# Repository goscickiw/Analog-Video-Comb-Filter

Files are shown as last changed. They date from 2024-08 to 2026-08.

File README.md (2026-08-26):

# Analog-Video-Comb-Filter
Analog Composite Video to S-Video comb filter board using SAA4960, SAA4961 or SAA4963 integrated circuit.

## **WARNING**
**This project uses end-of-life components that are no longer manufactured. If you want to build this, make sure that you can obtain all components before starting. Used or new-old-stock parts can sometimes be found online.**

## Description

This is a fully analog alternative to digital comb filters such as Extron YCS Transcoder or YCS 100. [That doesn't mean it will give better results though](#image-comparison---no-filter-lc-filter-and-comb-filters). I just made it because I didn't find any fully analog device like that on the market and I wanted one.

The comb filter is used to convert a composite video signal into an S-Video (Y/C) signal. Comb filters are much better than passive LC filters usually built into composite video displays, as they can preserve the frequencies of luminance that overlap with chrominance, providing higher image detail while removing dot crawl, and remove those overlapping luminance frequencies from the chrominance signal which reduces color artifacts.

When using the SAA4960 integrated circuit, PAL B, D, G, H and I systems are supported.

SAA4961 provides aditional support for PAL M, N and NTSC M systems.

When using the SAA4963 integrated circuit, only the NTSC M system is supported.

The board is designed to fit inside a KRADEX Z-76 enclosure.

### Circuit description

Circuit diagram

A composite video signal is fed in through an RCA connector (J4). The signal is terminated with a 75 ohm resistor and fed to U3 (or U7), U4 and U6 through 100 nF capacitors.

The LM1881 sync separator (U6) uses the composite video signal to generate a burst gate signal. The burst gate signal passes through a 74HC04 inverter (U5) to the MC44144 subcarrier PLL (U4).

U4 uses the composite video signal and the burst gate signal to generate a subcarrier frequency synchronized to the colorburst of the composite video signal. This subcarrier signal is then passed to the FSC input of U3/U7.

The SAA4960/61/63 comb filter (U3 or U7) is fed with the composite video signal and the synchronized subcarrier signal. The jumpers SYS1 and SYS2 set the video standard, and the jumper LPF can be used to disable the input low-pass filter. This circuit outputs filtered luminance and chrominance signals and a delayed composite video passthrough signal (when using SAA4963, the CVBYP jumper has to be shorted to allow non-delayed composite video passthrough). Those signals are then fed to the output amplifiers.

The AD813 triple op-amp (U2) is used for the output amplifiers. The output signals from the SAA4960/61[^1] are DC-biased by around 1V, so a non-rail-to-rail op-amp like the AD813 is viable. The gain can be adjusted from approx. 1,5x to 2,5x with RV1, RV2 and RV3.

## Pictures

| Assembled rev.2 devices (PAL and NTSC) | Completed, operating device in enclosure |
| --- | --- |
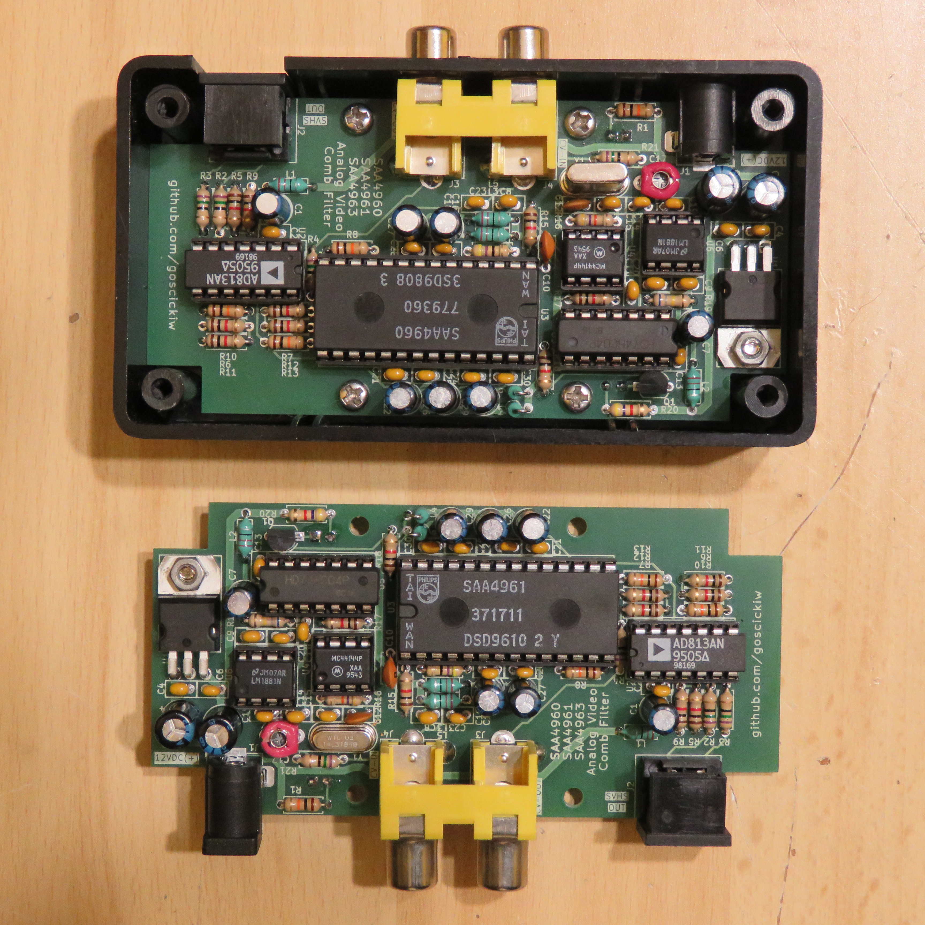
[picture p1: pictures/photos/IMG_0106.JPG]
Assembled devices
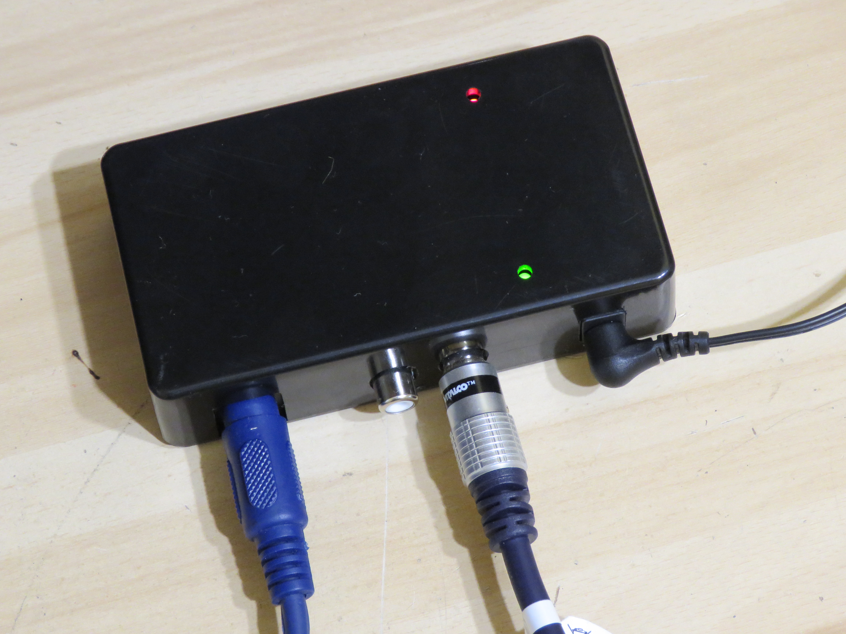
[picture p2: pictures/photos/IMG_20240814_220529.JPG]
Completed device
|  |  |

### Image comparison - no filter, LC filter and comb filters

<table>
  <tr>
    <th width="50%">No filter</th>
    <th width="50%">LC filter</th>
  </tr>
  <tr>
    <td>Luminance detail is preserved, but dot crawl is visible across the entire picture.</td>
    <td>Dot crawl is mostly removed, but luminance loses some sharpness, and higher frequency luminance components (responsible for sharpness) are left in chrominance causing color artifacts.</td>
  </tr>
  <tr>
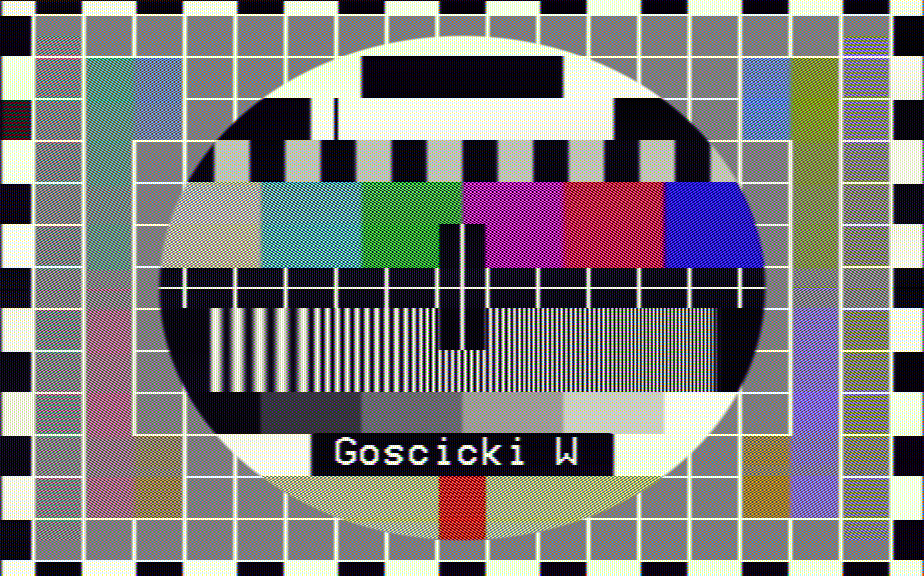
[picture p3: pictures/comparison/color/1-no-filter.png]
    <td></td>
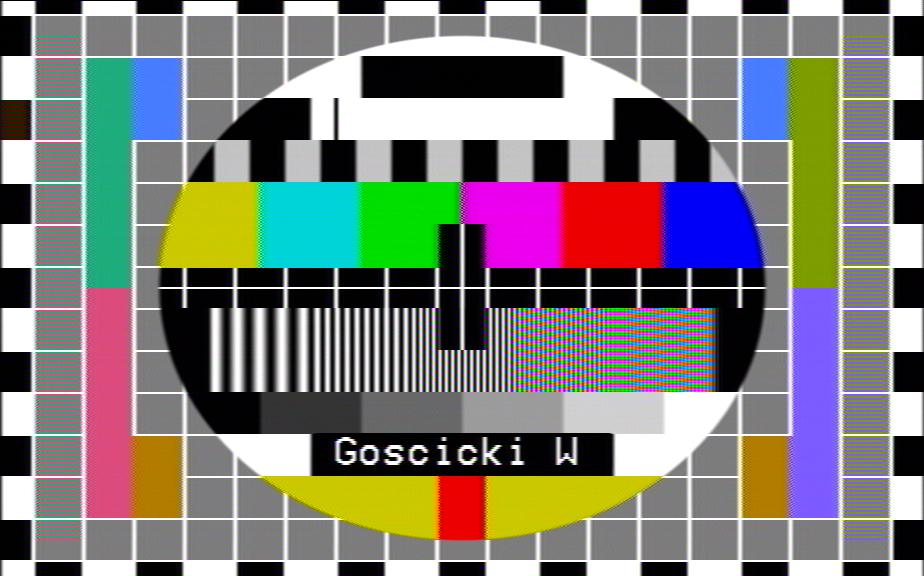
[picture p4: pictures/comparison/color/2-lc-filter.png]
    <td></td>
  </tr>
  <tr>
    <td></td>
    <td></td>
  </tr>
  <tr>
    <th>This analog comb filter</th>
    <th>MC141627 digital comb filter (for comparison, Extron YCS transcoder)</th>
  </tr>
  <tr>
    <td>Dot crawl is mostly removed and luminance sharpness is mostly preserved. Higher frequency luminance components are properly separated from chrominance.</td>
    <td>More effective than the analog comb filter.</td>
  </tr>
  <tr>
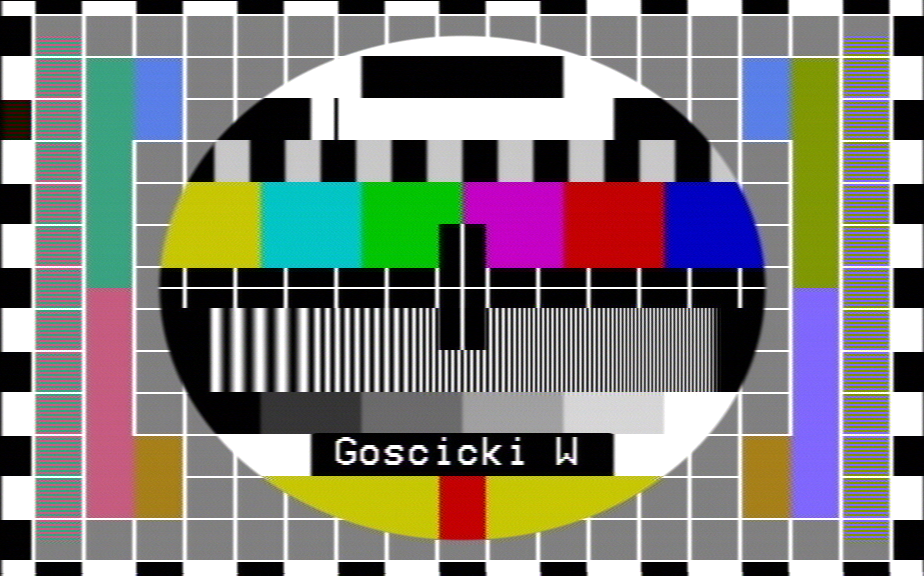
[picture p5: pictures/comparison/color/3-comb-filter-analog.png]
    <td></td>
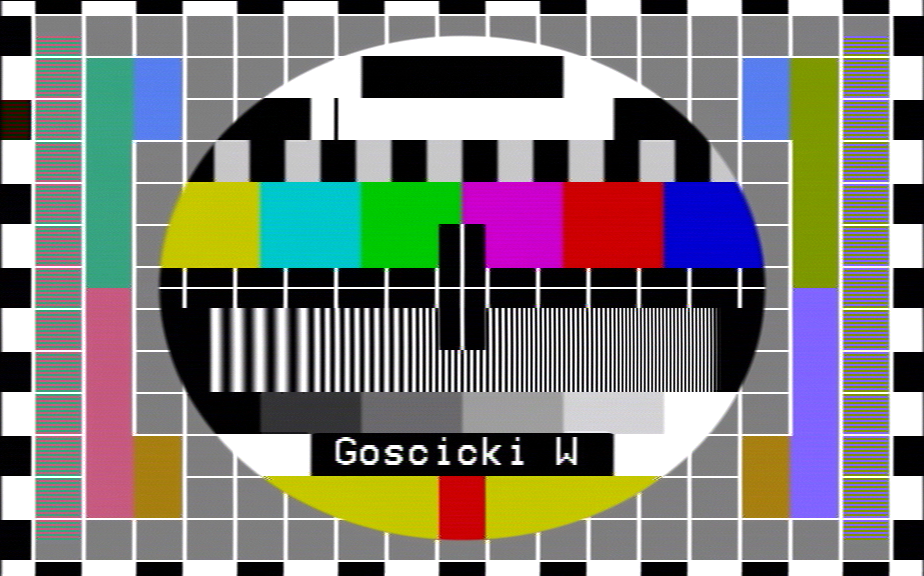
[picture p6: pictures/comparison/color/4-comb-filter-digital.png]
    <td></td>
  </tr>
</table>

<details>
  <summary>Monochrome image comparison</summary>
  <table>
    <tr>
      <th width="50%">No filter</th>
      <th width="50%">LC filter</th>
    </tr>
    <tr>
      <td>Luminance detail is preserved, but dot crawl is visible in colored sections.</td>
      <td>Dot crawl is mostly removed, but luminance loses some sharpness.</td>
    </tr>
    <tr>
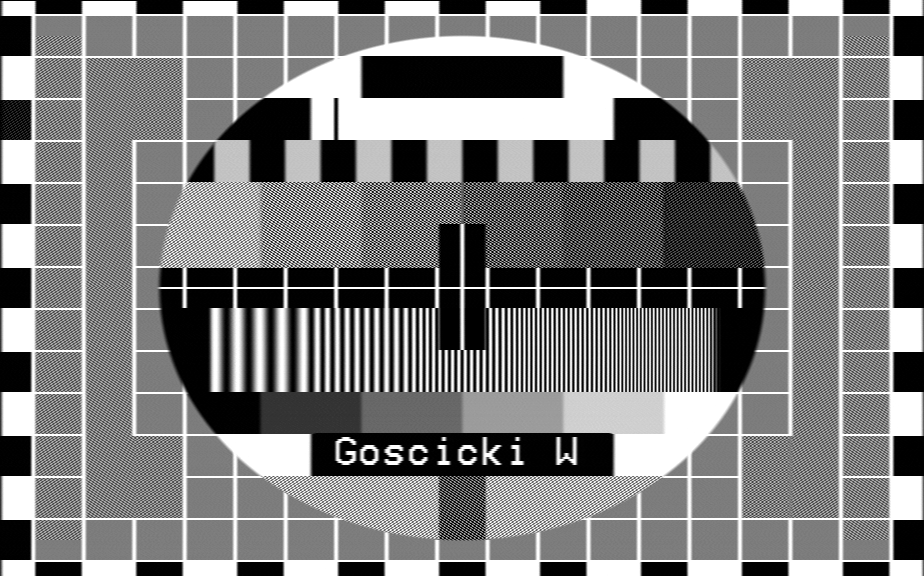
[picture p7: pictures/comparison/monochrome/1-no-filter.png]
      <td></td>
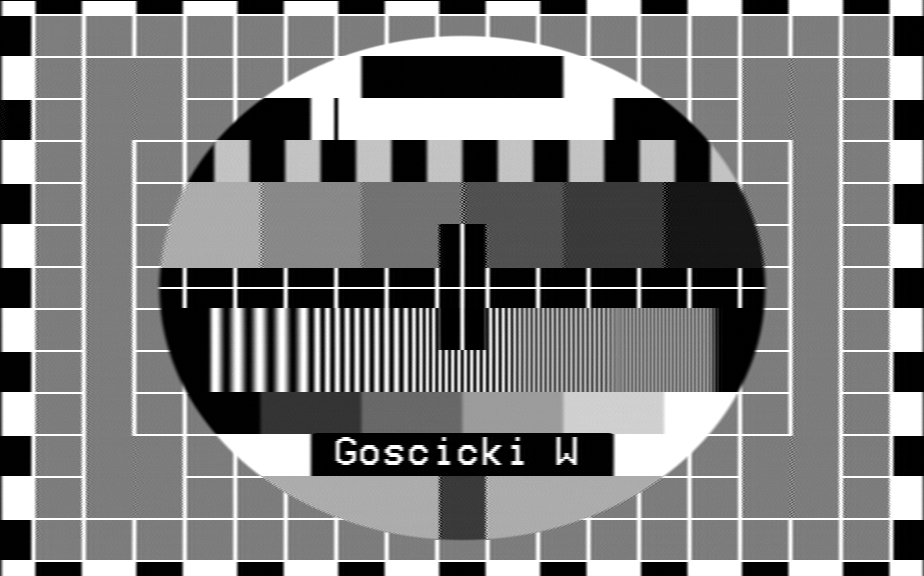
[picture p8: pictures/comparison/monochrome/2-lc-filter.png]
      <td></td>
    </tr>
    <tr>
      <td></td>
      <td></td>
    </tr>
    <tr>
      <th>This analog comb filter</th>
      <th>MC141627 digital comb filter (for comparison, Extron YCS transcoder)</th>
    </tr>
    <tr>
      <td>Dot crawl is mostly removed and luminance sharpness is mostly preserved.</td>
      <td>More effective than the analog comb filter.</td>
    </tr>
    <tr>
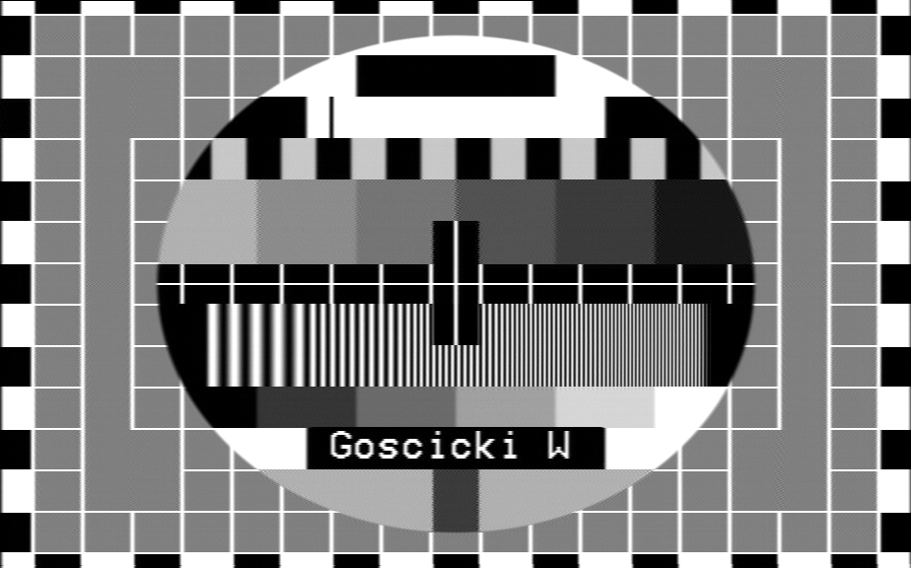
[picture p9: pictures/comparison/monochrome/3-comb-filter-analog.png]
      <td></td>
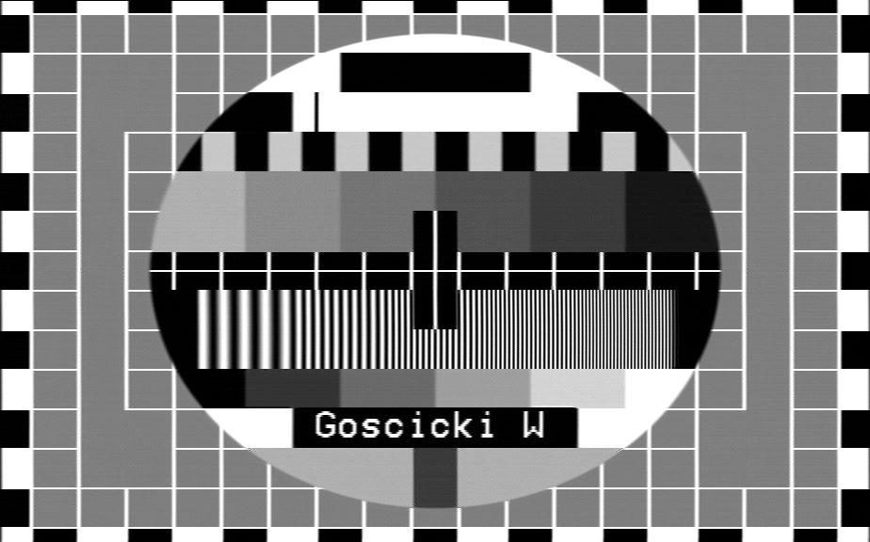
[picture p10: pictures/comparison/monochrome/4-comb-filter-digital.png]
      <td></td>
    </tr>
  </table>
</details>

## LEDs

D1 shows that the device is receiving power.

D2 shows that the comb filter is operating (U3 is in COMB mode). I'm not sure if U3 will ever *not* be in COMB mode when used in this circuit, so this LED might be unnecessary. SAA4963 does not have the output needed by this LED, so if it is used, then R19, R20, D2 and Q1 can be left unpopulated.

## REFDL filter capacitors

When using SAA4960 or SAA4961, install C24 and C26, and leave C31 and C32 unpopulated.

When using SAA4963, install C31 and C32, and leave C24 and C26 unpopulated.

## Solder jumper settings

### Standard selection jumpers (SYS1, SYS2)

SAA4961 only. When using SAA4960, SYS1 and SYS2 jumpers should be left open. When using SAA4963, the jumpers are not connected.

Appropriate crystal for the subcarrier oscillator should be installed depending on the jumper setting. If the standard is going to be changed frequently, it may be possible to install a socket for the crystal, however it should be taken into account that MC44144 is sensitive to additional capacitance at the crystal.

| Standard | SYS1  | SYS2  | Crystal required | 
| --- | ----- | ----- | --- |
| PAL B/D/G/H/I | Open  | Open  | 17,734475 MHz |
| PAL M | Open  | Short | 14,302444 MHz |
| PAL N | Short | Open  | 14,328225 MHz |
| NTSC M | Short | Short | 14,31818 MHz |

### Low pass filter jumper (LPF)

The SAA4960, SAA4961 and SAA4963 integrated circuits have a built-in low-pass filter on the composite video input. With SAA4960 and SAA4961, this filter can be disabled by shorting the LPF jumper, but it's recommended to leave it on. With SAA4963, the jumper is not connected and the filter is always on.

| LPF | Filter mode |
| ----- | --- |
| Open  | Filter enabled  |
| Short | Filter disabled |

### Composite video passthrough jumper (CVBYP)

SAA4963 doesn't have a composite video output, so the CVBYP jumper was provided for composite video passthrough. When the jumper is shorted, the video signal for composite video output is taken from pin 13 (composite video input) of SAA4963. The DC bias for the output amplifier is provided by the clamping circuit inside SAA4963. Do not install R12 to avoid additional load to the clamping circuit. This configuration has not been tested and may not work correctly. Leave the jumper open if shorting it causes issues for the comb filter.

**WARNING: This jumper must never be shorted if using SAA4960/61.**

| CVBYP | Usage |
| ----- | --- |
| Open  | When using SAA4960 or SAA4961. |
| Short | When using SAA4963. |

## Adjustment

After assembly, including setting the jumpers and installing the correct crystal depending on the analog video standard, the variable capacitor C17 will have to be adjusted so that the PLL locks correctly to the color subcarrier and the loop control voltage is centered.

Use the following procedure for adjustment:

1. Connect an EBU (for PAL) or SMPTE (for NTSC) color bar signal from a good quality reference source to the composite video input.
2. Connect a 10x oscillososcope probe to U4 pin 3 (phase detector output loop filter). Use AC coupling, 200 mV/div vertical scale, and 100 µs/div timebase.
3. Here are the reference pictures needed for the following steps:

<details>
  <summary>PAL waveforms</summary>
  <table>
    <tr>
      <th width="33%">Not locked</th>
      <th width="33%">Locked, not adjusted</th>
      <th width="33%">Best adjustment</th>
    </tr>
    <tr>
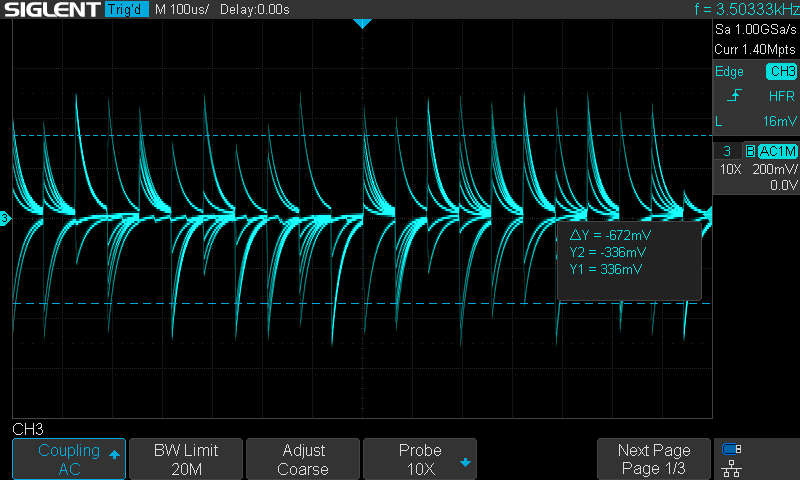
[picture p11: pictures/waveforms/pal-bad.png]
      <td></td>
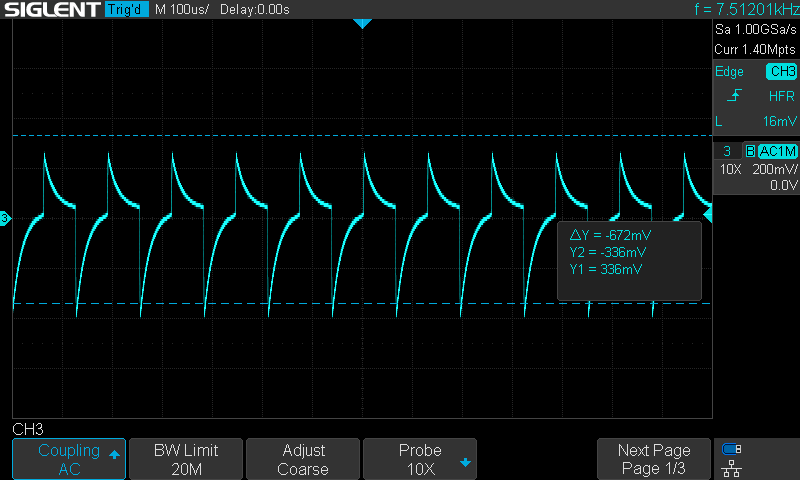
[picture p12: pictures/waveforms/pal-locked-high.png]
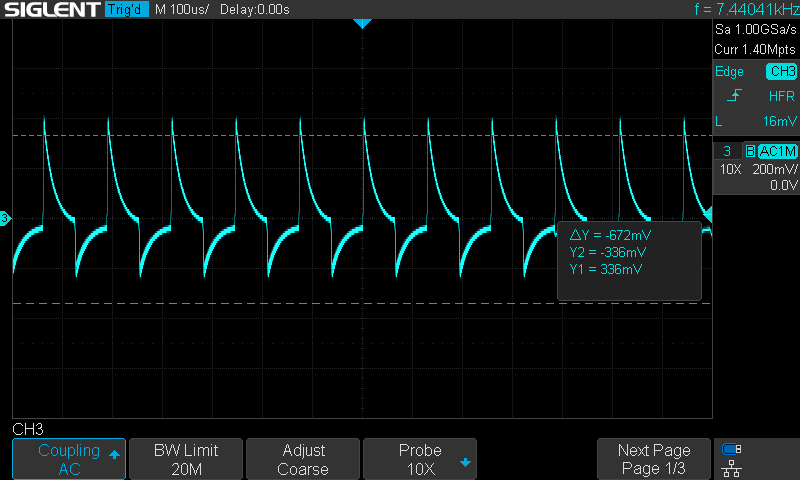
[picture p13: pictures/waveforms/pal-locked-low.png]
      <td><br/></td>
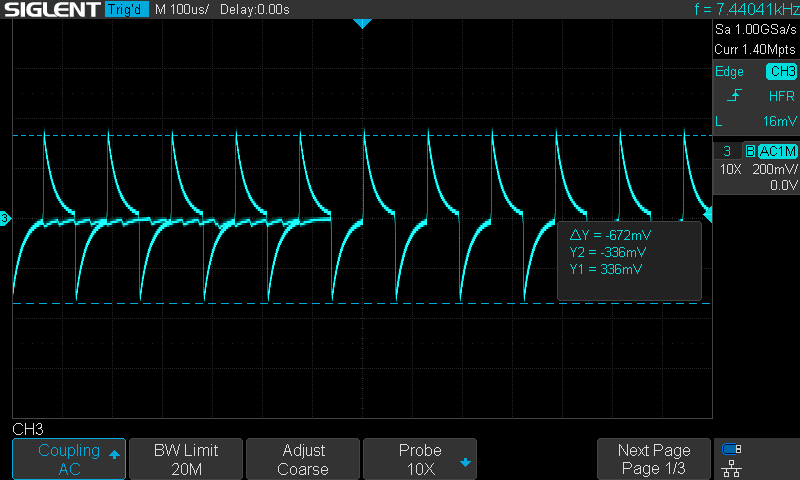
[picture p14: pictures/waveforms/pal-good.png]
      <td></td>
    </tr>
  </table>
</details>

<details>
  <summary>NTSC waveforms</summary>
  <table>
    <tr>
      <th width="33%">Not locked</th>
      <th width="33%">Locked, not adjusted</th>
      <th width="33%">Best adjustment</th>
    </tr>
    <tr>
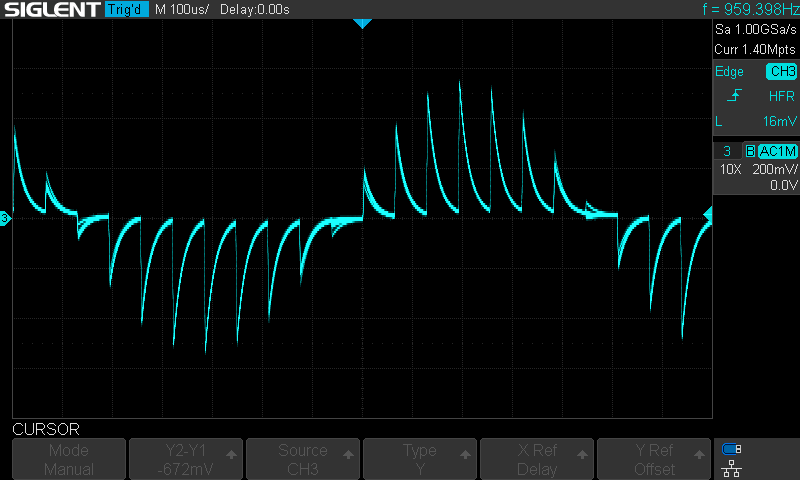
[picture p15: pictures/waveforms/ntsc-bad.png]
      <td></td>
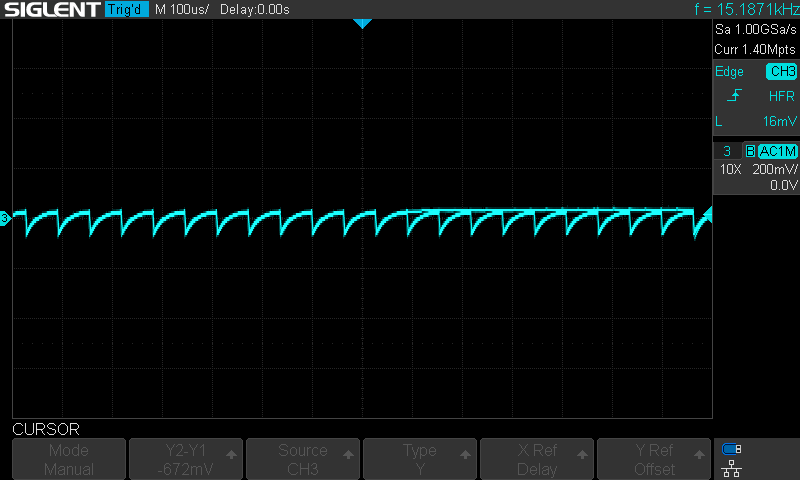
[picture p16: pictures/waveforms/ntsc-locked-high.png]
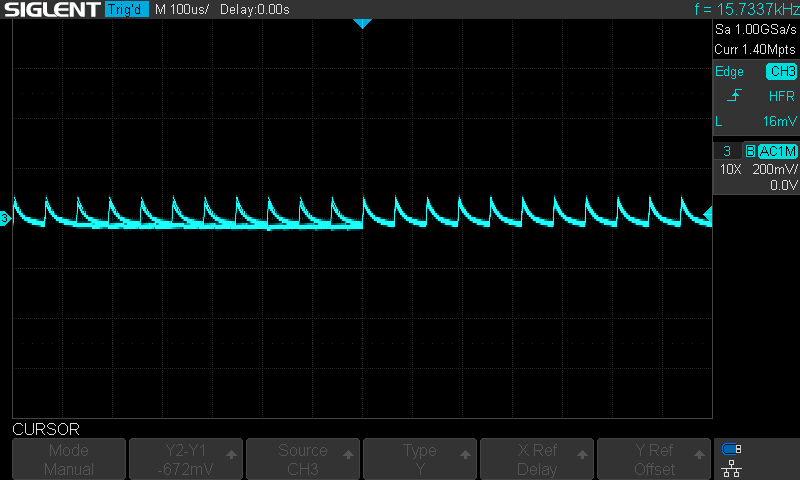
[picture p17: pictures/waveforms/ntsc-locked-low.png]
      <td><br/></td>
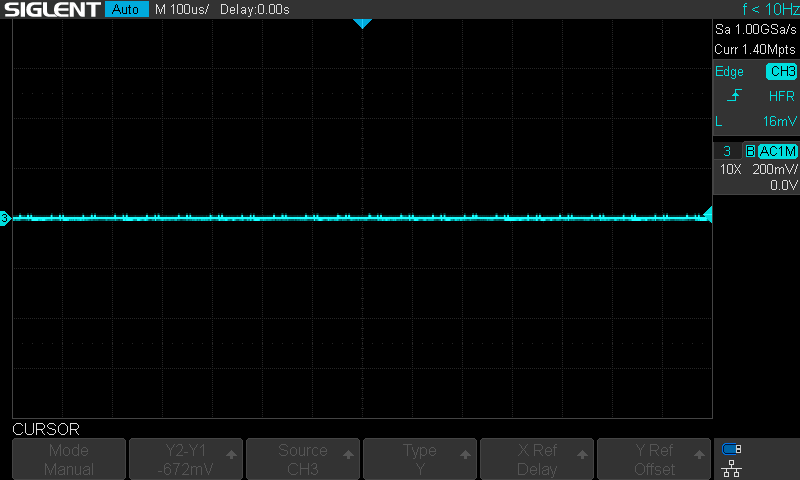
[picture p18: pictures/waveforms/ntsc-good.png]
      <td></td>
    </tr>
  </table>
</details>

4. Follow the flow chart below:

```mermaid
flowchart LR
  A{Able to obtain waveform shown in <b>Best&nbsp;adjustment</b> by adjusting C17?} -- Yes --> B([PLL correctly adjusted.]);
  A -->|No| C{"PLL able to lock (one of <b>Locked,&nbsp;not&nbsp;adjusted</b> waveforms)?"};
  C -->|Yes| D{Does waveform resemble the <b>top</b> or <b>bottom</B> picture in <b>Locked,&nbsp;not&nbsp;adjusted</b>?};
  C -->|No| E["Measure frequency at U4 pin 1 (FSC output), and adjust C17 to get as close as possible to required frequency."];
  E --> F{Is the frequency higher or lower than required?};
  F -->|Higher| G[replace C17 with a higher max. value trim capacitor, or add a parallel capacitor.];
  F -->|Lower| H[replace C17 with a lower min. value trim capacitor.];
  D -->|Top| G;
  D -->|Bottom| H;
  G --> I[Adjust C17 and observe the waveform at U4 pin 3.] --> A;
  H --> I;
```

5. Set RV1, RV2, RV3 to center position. Connect the luminance, chrominance and composite outputs to an oscilloscope with 75 ohm load resistance. Luminance signal is preferred for oscilloscope trigger. Adjust RV1, RV2, RV3 to obtain the following:

<table>
  <tr>
    <th>Output</th>
    <th>Adjustment</th>
    <th>Measured value</th>
    <th>PAL</th>
    <th>NTSC</th>
  </tr>
  <tr>
    <td>Chrominance</td>
    <td>RV1</td>
    <td>Peak-peak <b>colorburst</b></td>
    <td>300 mV</td>
    <td>285,72 mV</td>
  </tr>
  <tr>
    <td>Luminance</td>
    <td>RV2</td>
    <td rowspan=2>Peak-peak voltage<br/>(sync level to 100% white level)</td>
    <td rowspan=2 colspan=2>1 V</td>
  </tr>
  <tr>
    <td>Composite</td>
    <td>RV3</td>
  </tr>
</table>

Readjustment is necessary if the crystal and the standard selection jumper settings are changed.

## Parts list

### Resistors

| Resistance | Power  | Qty |
| --- | --- | --- |
| 47 Ω | 0,25 W | 1 |
| 75 Ω | 0,25 W | 4 |
| 470 Ω | 0,25 W | 3 |
| 1 kΩ | 0,25 W | 6 |
| 4,7 kΩ | 0,25 W | 1 |
| 10 kΩ | 0,25 W | 4 |
| 47 kΩ | 0,25 W | 1 |
| 680 kΩ | 0,25 W | 1 |

### Capacitors

| Capacitance | Pin pitch | Type | Qty |
| --- | --- | --- | --- |
| 4-20 pF | 5,08 mm | Ceramic variable | 1 |
| 470 pF | 2,5 mm | Ceramic | 1 |
| 1 nF | 5 mm | Ceramic | 1 |
| 100 nF | 2,5 mm | Ceramic | 18  |
| 100 μF | 2 mm | Electrolytic, ≥6,3V, ⌀5mm  | 6 |
| 100 μF | 2 mm | Electrolytic, ≥16V, ⌀5mm | 1 |
| 220 μF | 2,5 mm | Electrolytic, ≥16V, ⌀6,3mm | 2 |

### Inductors

| Inductance | Max. Current | Exact part | Qty |
| --- | --- | --- | --- |
| 22 μH | 0,285 A | Ferrocore DLA22-N | 6 |

### Semiconductors

| Type | Model | Qty |
| --- | --- | --- |
| LED | 3mm Green | 1 |
| LED | 3mm Red | 1 |
| NPN Transistor | BC548 | 1 |

### Integrated circuits

| Model | Package | Qty |
| --- | --- | --- |
| L7805 | TO220 | 1 |
| AD813 or AD8044 | DIP14 | 1 |
| SAA4960 or SAA4961 or SAA4963 | DIP28 (SAA4960/61) or DIP20 (SAA4963) | 1 |
| MC44144 | DIP8 | 1 |
| 74HC04 | DIP14 | 1 |
| LM1881 | DIP8 | 1 |

### Other

| Type | Model | Qty |
| --- | --- | --- |
| Potentiometer | PIHER PT10LH-1K | 3 |
| Crystal | HC-49U, depends on video system | 1 |
| RCA Connector | Keystone Electronics 973 | 2 |
| Mini-DIN Connector | MDC-204, unshielded | 1 |
| DC Barrel Jack | Generic 5,5/2,5mm | 1 |
| Enclosure | KRADEX Z-76 | 1 |

## License

This work is licensed under CC BY-SA 4.0 license.

[^1]: SAA4963 has not been tested as I don't have one yet.

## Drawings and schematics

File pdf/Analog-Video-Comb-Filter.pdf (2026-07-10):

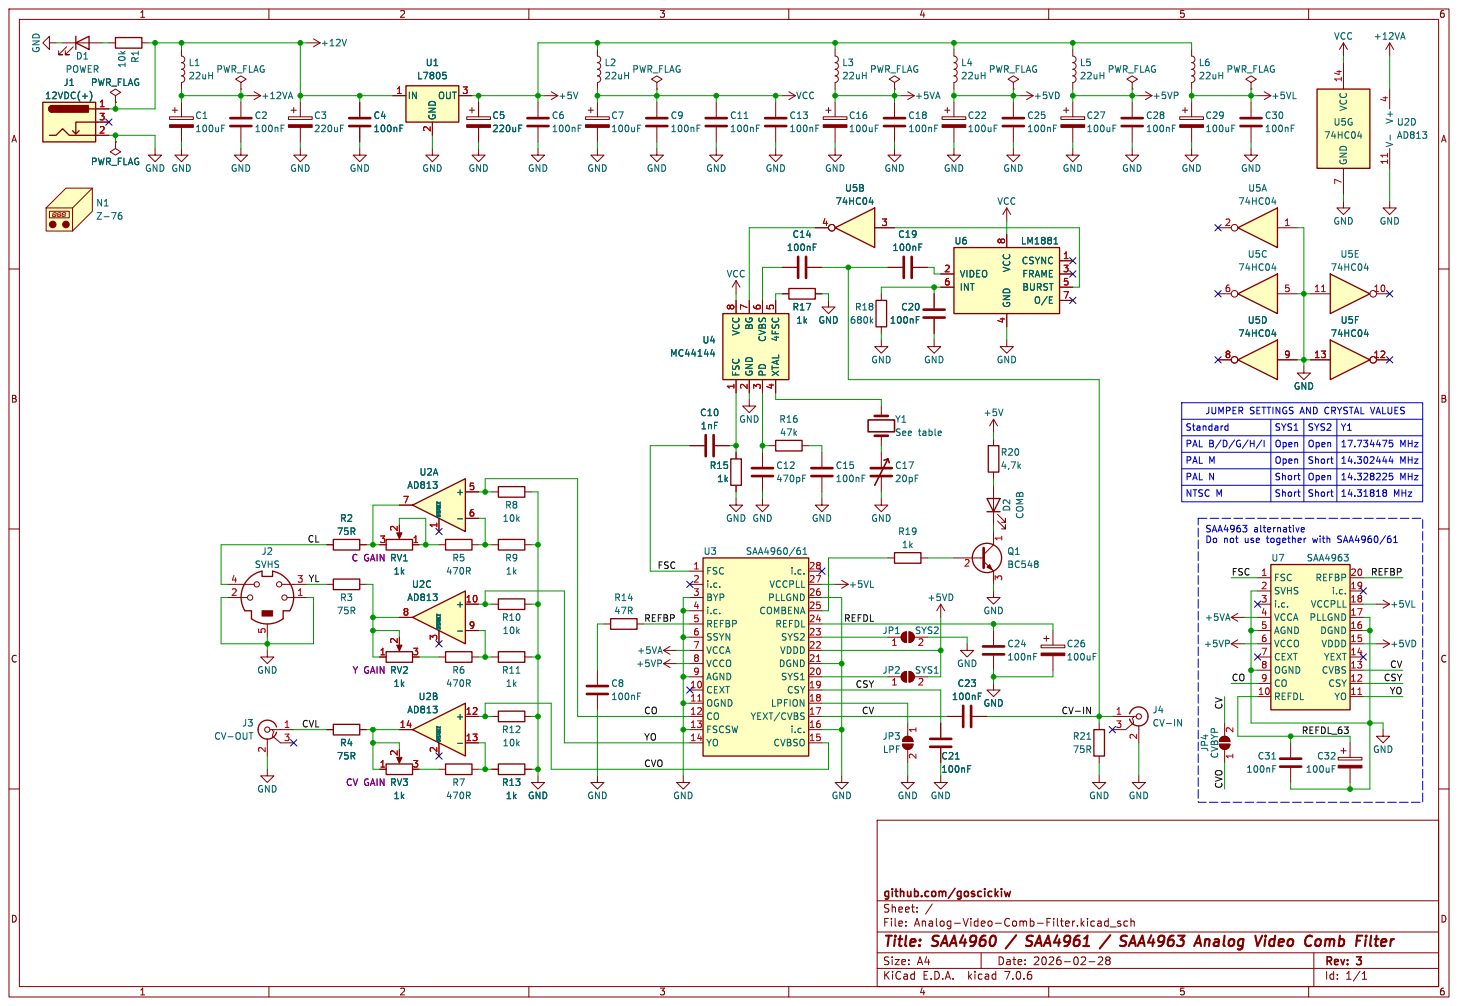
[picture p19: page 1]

Y1 Short JUMPER SETTINGS AND CRYSTAL VALUES
Open Short PAL M

Id: 1/1 Title: SAA4960 / SAA4961 / SAA4963 Analog Video Comb Filter File: Analog-Video-Comb-Filter.kicad_sch Sheet: / github.com/goscickiw

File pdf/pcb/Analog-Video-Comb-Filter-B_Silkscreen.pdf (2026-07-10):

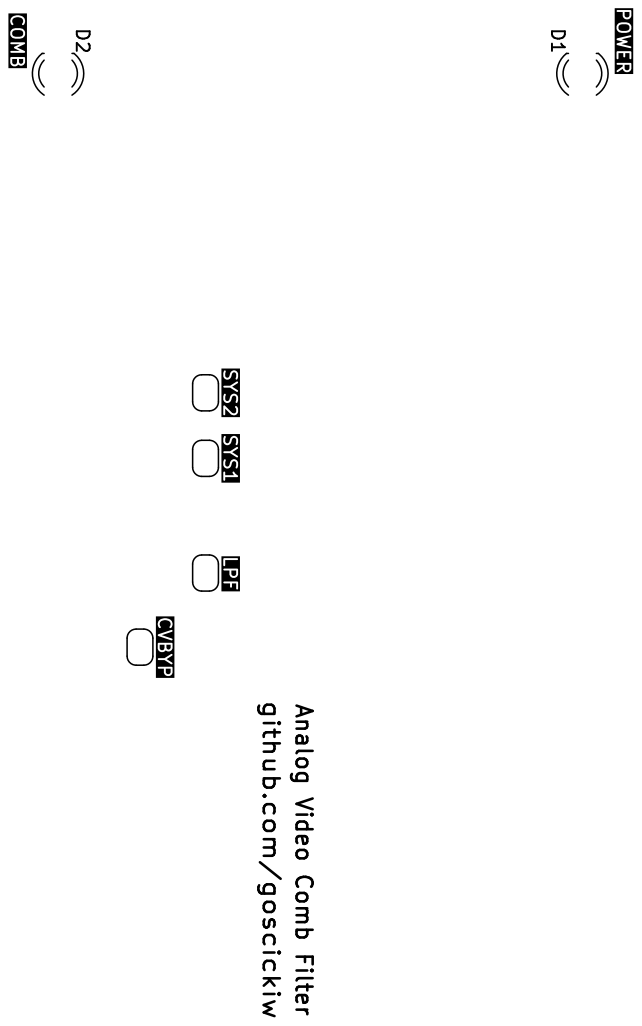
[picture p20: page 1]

Analog Video Comb Filter github.com/goscickiw D2 D1

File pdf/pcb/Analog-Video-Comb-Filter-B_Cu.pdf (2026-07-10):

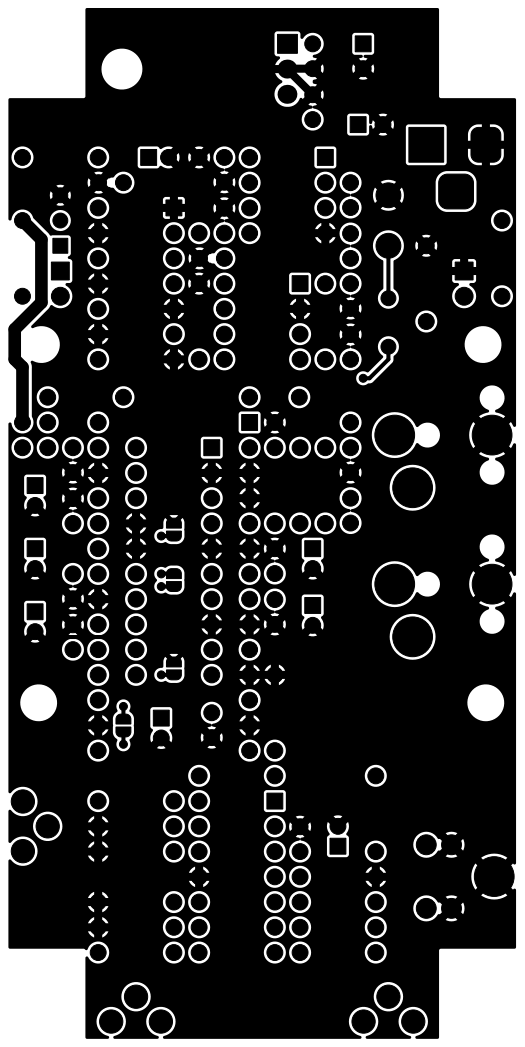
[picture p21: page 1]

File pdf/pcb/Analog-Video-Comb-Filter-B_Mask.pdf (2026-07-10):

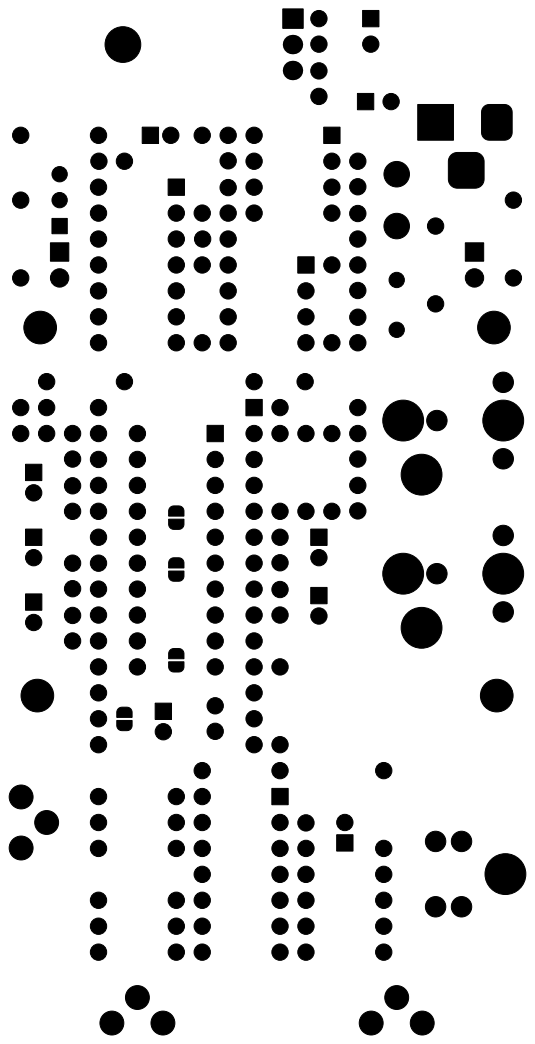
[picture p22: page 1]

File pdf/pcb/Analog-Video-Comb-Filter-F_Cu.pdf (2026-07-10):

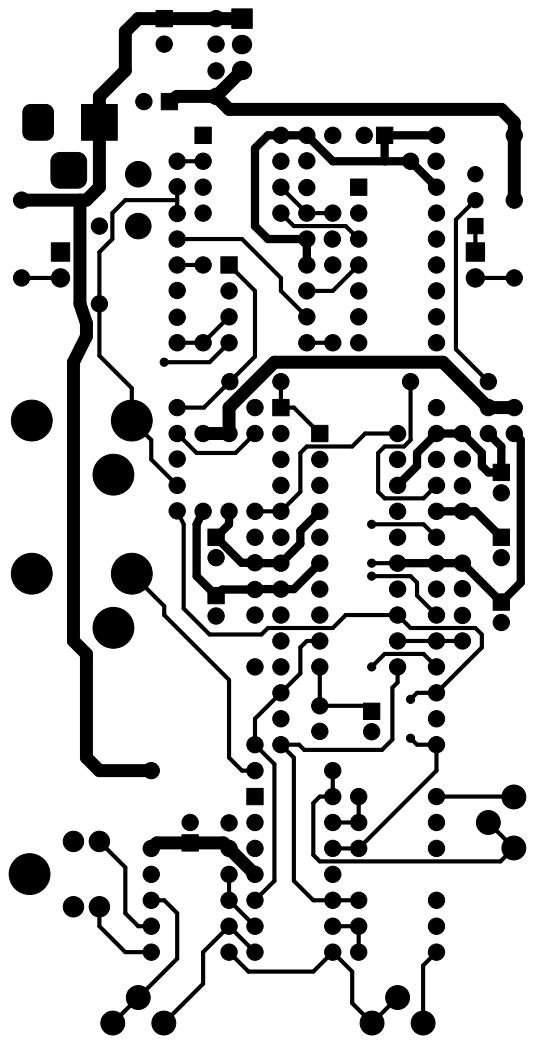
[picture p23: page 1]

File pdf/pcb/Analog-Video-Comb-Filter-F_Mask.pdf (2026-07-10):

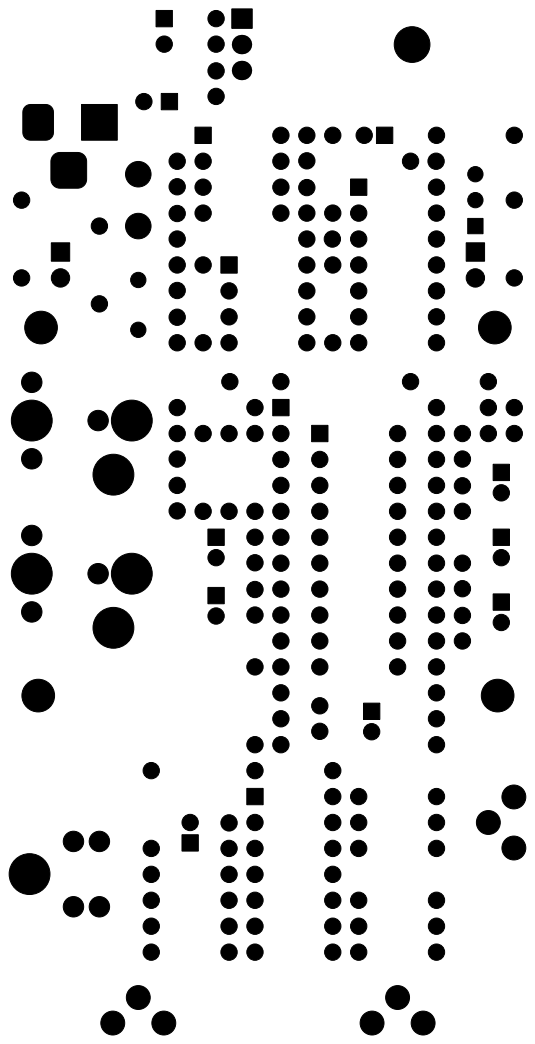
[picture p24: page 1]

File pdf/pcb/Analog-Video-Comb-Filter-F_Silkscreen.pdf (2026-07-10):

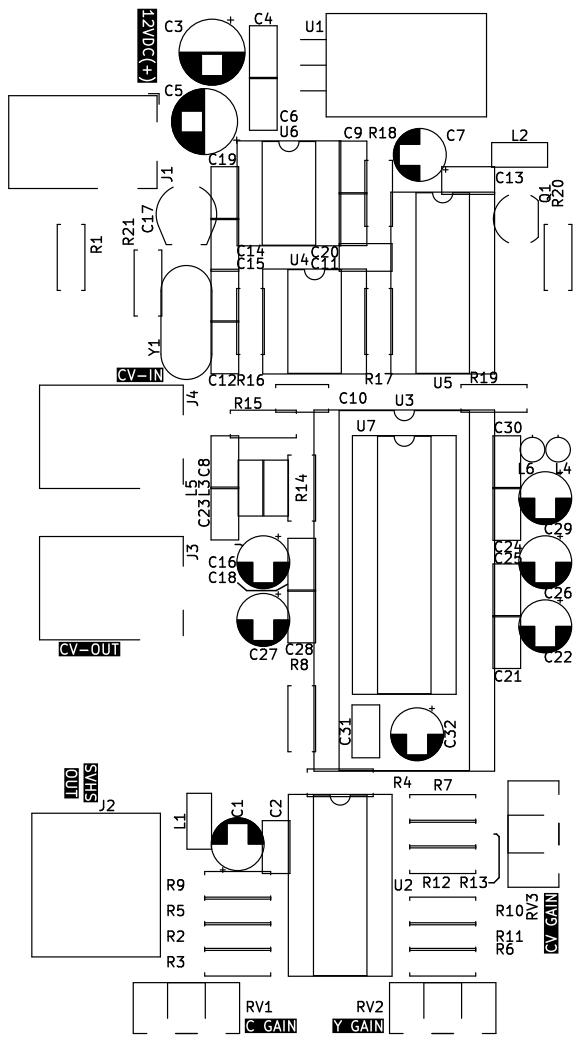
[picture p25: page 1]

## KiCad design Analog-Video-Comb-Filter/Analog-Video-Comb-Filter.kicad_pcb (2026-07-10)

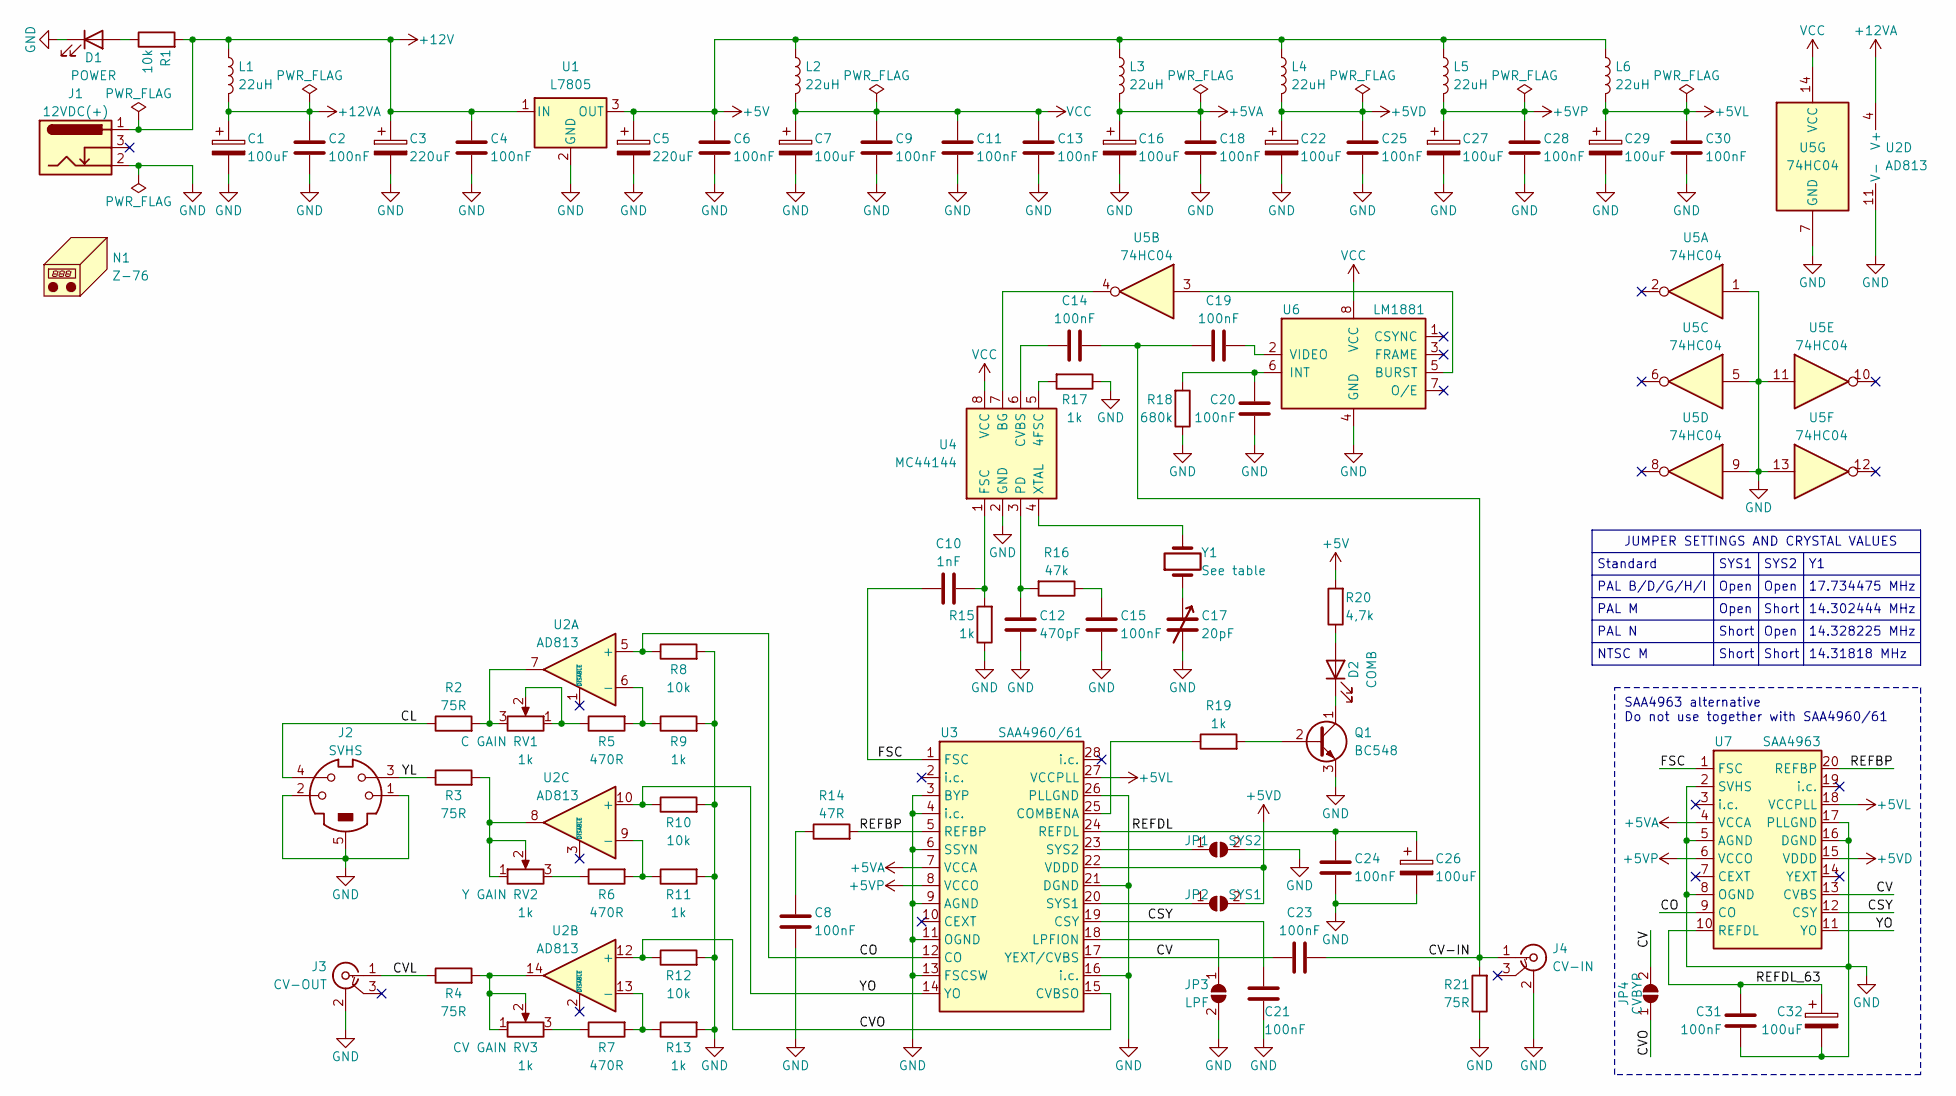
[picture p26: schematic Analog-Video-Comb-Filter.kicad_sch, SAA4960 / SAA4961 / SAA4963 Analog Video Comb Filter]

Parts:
C1, C7, C16, C22, C26, C27, C29, C32: 100uF; CP_Radial_D5.0mm_P2.00mm
C2, C4, C6, C8, C9, C11, C13, C14, C15, C18, C19, C20, C21, C23, C24, C25, C28, C30, C31: 100nF; C_Disc_D5.0mm_W2.5mm_P2.50mm
C3, C5: 220uF; CP_Radial_D6.3mm_P2.50mm
C10: 1nF; C_Disc_D5.0mm_W2.5mm_P5.00mm
C12: 470pF; C_Disc_D5.0mm_W2.5mm_P2.50mm
C17: 20pF; C_Trimmer_D6.0mm_P5.08mm
D1: POWER; LED_D3.0mm
D2: COMB; LED_D3.0mm
J1: 12VDC(+); BarrelJack_Horizontal
J2: SVHS; MDC-204
J3: CV-OUT; Keystone_973
J4: CV-IN; Keystone_973
JP1: SYS2; SolderJumper-2_P1.3mm_Open_RoundedPad1.0x1.5mm
JP2: SYS1; SolderJumper-2_P1.3mm_Open_RoundedPad1.0x1.5mm
JP3: LPF; SolderJumper-2_P1.3mm_Open_RoundedPad1.0x1.5mm
JP4: CVBYP; SolderJumper-2_P1.3mm_Open_RoundedPad1.0x1.5mm
L1, L2, L3, L5: 22uH; L_Axial_L5.3mm_D2.2mm_P7.62mm_Horizontal_Vishay_IM-1
L4, L6: 22uH; L_Axial_L5.3mm_D2.2mm_P2.54mm_Vertical_Vishay_IM-1
N1: Z-76
Q1: BC548; TO-92_Inline_Wide
R1, R8, R10, R12: 10k; R_Axial_DIN0207_L6.3mm_D2.5mm_P7.62mm_Horizontal
R2, R3, R4, R21: 75R; R_Axial_DIN0207_L6.3mm_D2.5mm_P7.62mm_Horizontal
R5, R6, R7: 470R; R_Axial_DIN0207_L6.3mm_D2.5mm_P7.62mm_Horizontal
R9, R11, R13, R15, R17, R19: 1k; R_Axial_DIN0207_L6.3mm_D2.5mm_P7.62mm_Horizontal
R14: 47R; R_Axial_DIN0207_L6.3mm_D2.5mm_P7.62mm_Horizontal
R16: 47k; R_Axial_DIN0207_L6.3mm_D2.5mm_P7.62mm_Horizontal
R18: 680k; R_Axial_DIN0207_L6.3mm_D2.5mm_P7.62mm_Horizontal
R20: 4,7k; R_Axial_DIN0207_L6.3mm_D2.5mm_P7.62mm_Horizontal
RV1, RV2, RV3: 1k; Potentiometer_Piher_PT-10-H01_Horizontal
U1: L7805; TO-220-3_Horizontal_TabDown
U2: AD813; DIP-14_W7.62mm_Socket
U3: SAA4960/61; DIP-28_W15.24mm_Socket
U4: MC44144; DIP-8_W7.62mm_Socket
U5: 74HC04; DIP-14_W7.62mm_Socket
U6: LM1881; DIP-8_W7.62mm_Socket
U7: SAA4963; DIP-20_W7.62mm_Socket
Y1: See table; Crystal_HC49-U_Vertical

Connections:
+5V: C5.1, C6.1, L2.1, L3.1, L4.2, L5.1, L6.2, R20.2, U1.3 (OUT)
+5VA: C16.1, C18.1, L3.2, U3.7 (VCCA), U7.4 (VCCA)
+5VD: C22.1, C25.1, JP2.2 (B), L4.1, U3.22 (VDDD), U7.15 (VDDD)
+5VL: C29.1, C30.1, L6.1, U3.27 (VCCPLL), U7.18 (VCCPLL)
+5VP: C27.1, C28.1, L5.2, U3.8 (VCCO), U7.6 (VCCO)
+12V: C3.1, C4.1, J1.1, L1.1, R1.2, U1.1 (IN)
+12VA: C1.1, C2.1, L1.2, U2.4 (V+)
/CL: J2.4, R2.1
/CO: R8.1, U2.5 (+), U3.12 (CO), U7.9 (CO)
/CSY: C21.1, U3.19 (CSY), U7.12 (CSY)
/CV: C23.1, JP4.2 (B), U3.17 (YEXT/CVBS), U7.13 (CVBS)
/CV-IN: C14.2, C19.1, C23.2, J4.1 (In), R21.2
/CVL: J3.1 (In), R4.1
/CVO: JP4.1 (A), R12.1, U2.12 (+), U3.15 (CVBSO)
/FSC: C10.1, U3.1 (FSC), U7.1 (FSC)
/REFBP: R14.2, U3.5 (REFBP), U7.20 (REFBP)
/REFDL: C24.1, C26.1, U3.24 (REFDL)
/REFDL_63: C31.1, C32.1, U7.10 (REFDL)
/YL: J2.3, R3.1
/YO: R10.1, U2.10 (+), U3.14 (YO), U7.11 (YO)
GND: C1.2, C2.2, C3.2, C4.2, C5.2, C6.2, C7.2, C8.2, C9.2, C11.2, C12.2, C13.2, C15.2, C16.2, C17.2, C18.2, C20.2, C21.2, C22.2, C24.2, C25.2, C26.2, C27.2, C28.2, C29.2, C30.2, C31.2, C32.2, D1.1 (K), J1.2, J2.1, J2.2, J2.5, J3.2 (Ext), J4.2 (Ext), JP1.2 (B), JP3.2 (B), Q1.3 (E), R8.2, R9.2, R10.2, R11.2, R12.2, R13.2, R15.1, R17.1, R18.1, R21.1, U1.2 (GND), U2.11 (V-), U3.3 (BYP), U3.4 (i.c.), U3.6 (SSYN), U3.9 (AGND), U3.11 (OGND), U3.13 (FSCSW), U3.16 (i.c.), U3.21 (DGND), U3.26 (PLLGND), U4.2 (GND), U5.1, U5.5, U5.7 (GND), U5.9, U5.11, U5.13, U6.4 (GND), U7.2 (SVHS), U7.5 (AGND), U7.8 (OGND), U7.16 (DGND), U7.17 (PLLGND)
unnamed: C8.1, R14.1
unnamed: C15.1, R16.1
unnamed: C17.1, Y1.1
unnamed: D1.2 (A), R1.1
unnamed: D2.2 (A), R20.1
unnamed: D2.1 (K), Q1.1 (C)
unnamed: JP1.1 (A), U3.23 (SYS2)
unnamed: JP2.1 (A), U3.20 (SYS1)
unnamed: JP3.1 (A), U3.18 (LPFION)
unnamed: Q1.2 (B), R19.2
unnamed: R2.2, RV1.3, U2.7
unnamed: R3.2, RV2.1, RV2.2, U2.8
unnamed: R4.2, RV3.1, RV3.2, U2.14
unnamed: R5.1, RV1.1, RV1.2
unnamed: R6.1, RV2.3
unnamed: R7.1, RV3.3
unnamed: R5.2, R9.1, U2.6 (-)
unnamed: R7.2, R13.1, U2.13 (-)
unnamed: R6.2, R11.1, U2.9 (-)
unnamed: R19.1, U3.25 (COMBENA)
unnamed: R17.2, U4.5 (4FSC)
unnamed: U4.7 (BG), U5.4
unnamed: C14.1, U4.6 (CVBS)
unnamed: C10.2, R15.2, U4.1 (FSC)
unnamed: C12.1, R16.2, U4.3 (PD)
unnamed: U4.4 (XTAL), Y1.2
unnamed: U5.3, U6.5 (BURST)
unnamed: C20.1, R18.2, U6.6 (INT)
unnamed: C19.2, U6.2 (VIDEO)
VCC: C7.1, C9.1, C11.1, C13.1, L2.2, U4.8 (VCC), U5.14 (VCC), U6.8 (VCC)

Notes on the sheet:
SYS2
Short
PAL N
PAL M
SAA4963 alternative Do not use together with SAA4960/61
SYS1
14.302444 MHz
Open
14.328225 MHz
17.734475 MHz
NTSC M
14.31818 MHz
PAL B/D/G/H/I
Standard
JUMPER SETTINGS AND CRYSTAL VALUES

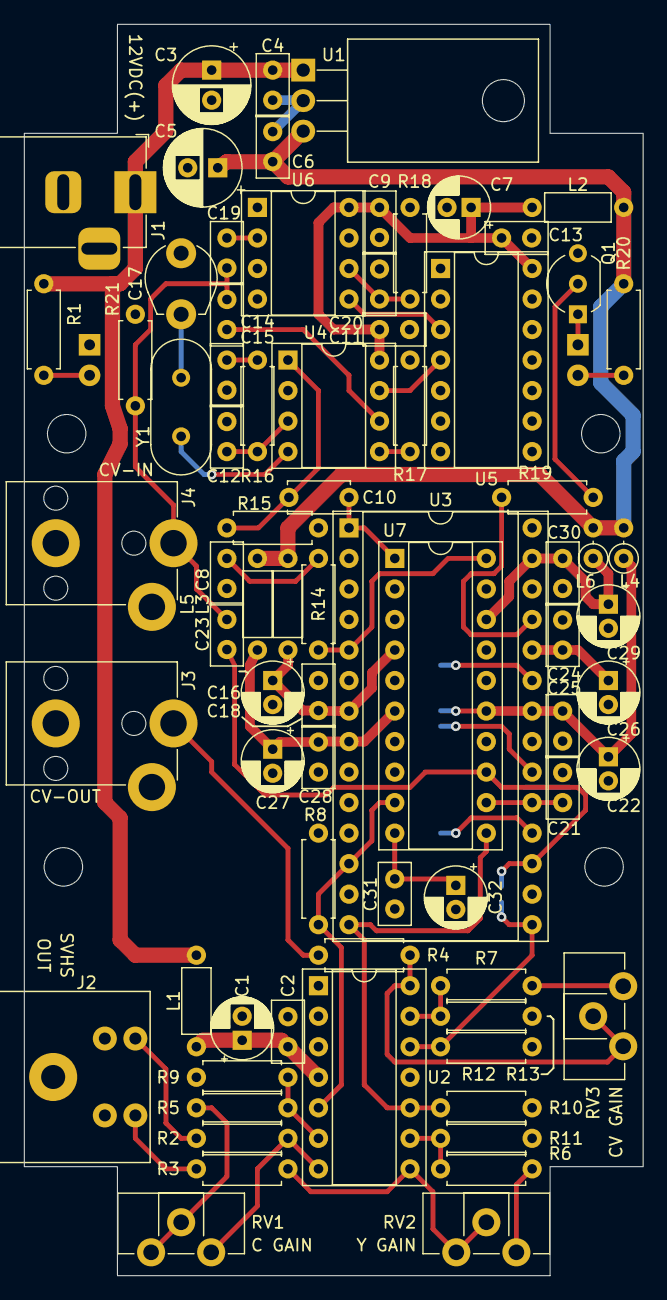
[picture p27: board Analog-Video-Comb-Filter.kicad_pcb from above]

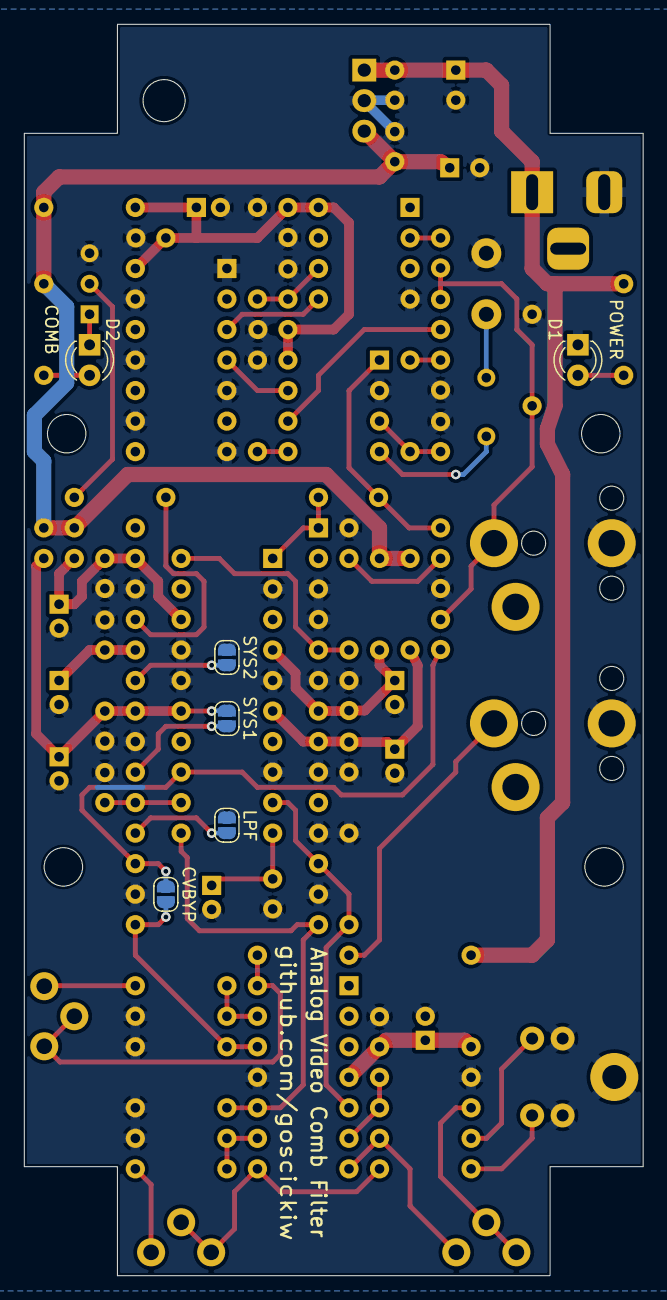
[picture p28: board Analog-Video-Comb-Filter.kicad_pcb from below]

Board: 2 copper layers, 51.5 x 104.1 mm, 82 parts (6 on the bottom side), 51 nets.

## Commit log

2024-08-31 Replaced RCA connector footprint, added gerber files, fixed README
    [Analog-Video-Comb-Filter-B_Cu.gbl, Analog-Video-Comb-Filter-B_Mask.gbs, Analog-Video-Comb-Filter-B_Silkscreen.gbo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]
2024-08-31 Better comparison images including LC filter
2024-09-28 Added alternative footprint for SAA4963
    [Analog-Video-Comb-Filter.kicad_pcb, Analog-Video-Comb-Filter.kicad_sch]
2024-09-28 Changed C24 to C21 as a result of KiCad auto-renumber
2024-09-28 Gerber files for SAA4963 version
    [Analog-Video-Comb-Filter-B_Cu.gbl, Analog-Video-Comb-Filter-B_Mask.gbs, Analog-Video-Comb-Filter-B_Silkscreen.gbo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]
2025-11-16 Improved PCB layout, readme improvements
    - Minimized (unfortunately not eliminated) ground plane interruptions under signal traces.
    - Added dedicated location for SAA4963 alternative footprint REFDL filter capacitors. This way they are not far away and the trace to them is not in the way of other traces.
    - Better routing of some traces around the SAA4963 alternative footprint.
    - More accurate description of PLL tuning method, with pictures.
    - Better quality comparison pictures.
    - Various other readme fixes.
    [Analog-Video-Comb-Filter-B_Cu.gbl, Analog-Video-Comb-Filter-B_Mask.gbs, Analog-Video-Comb-Filter-B_Silkscreen.gbo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]
2026-02-14 Corrected mistake in CVBYP jumper description
    The video input of the comb filter IC has a clamping circuit that provides a DC bias voltage, so adding extra DC biasing resistors might cause problems.
2026-02-14 New output amplifier design
    The BJT amplifiers have been replaced with high bandwidth rail-to-rail operational amplifiers. This should resolve the issue of the signal becoming malformed when load is connected through a capacitor, and maybe improve the frequency response as well. The old design has been moved to "rev1-bjt-output-amplifier" branch.
    [Analog-Video-Comb-Filter-B_Cu.gbl, Analog-Video-Comb-Filter-B_Mask.gbs, Analog-Video-Comb-Filter-B_Silkscreen.gbo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]
2026-02-21 Fixed numbering mistakes on PCB, fixed BOM, added color comparison images
    - Fixed incorrect R12, R13, R18 and R19 numbers on PCB.
    - Removed 560 ohm resistors from parts list.
    - Changed 2.2k resistor to 1k as its resistance wasn't critical, now there's one less different part.
    - Set solder jumpers and some mutually exclusive parts to be excluded from BOM generation.
    - Renamed documentation folder to pdf.
    - Added PCB layers in PDF form.
    - Added color comparison images, and moved the monochrome comparison images to a collapsible section.
    - Added rev.2 assembled PCB photo.
    [Analog-Video-Comb-Filter-B_Cu.gbl, Analog-Video-Comb-Filter-B_Mask.gbs, Analog-Video-Comb-Filter-B_Silkscreen.gbo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]
2026-02-21 AD813 tested and working, added circuit diagram to README
2026-07-10 Revision 3
    - Settled on AD813 as the output amplifier, this should also fix #1 as AD8044 is no longer used;
    - Added output gain adjustment.
    [Analog-Video-Comb-Filter-B_Cu.gbl, Analog-Video-Comb-Filter-B_Mask.gbs, Analog-Video-Comb-Filter-B_Silkscreen.gbo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]
2026-08-26 Update README.md
    Fixed broken flowchart
